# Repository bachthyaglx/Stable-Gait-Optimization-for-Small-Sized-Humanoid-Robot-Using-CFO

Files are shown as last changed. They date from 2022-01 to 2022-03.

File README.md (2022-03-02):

# Stable Gait Optimization for Small Sized Humanoid Robot Using CFO

This research proposes a new way to optimize the gait
design for human robots that allows stable stepping with preset
foot-lifting magnitude. The novel Central Force Optimization
(CFO) algorithm is used to optimize the gait parameters to help
humanoid robot walk steadily. The efficiency of the proposed
method is compared with the GA-Genetic Algorithm, PSOParticle
Swarm Optimization and improved differential
evolution algorithm (MDE-Modified Differential Evolution).
The simulated and experimental results applied on the smallsized
humanoid robot show that the newly proposed algorithm
offers an efficient and stable gait for humanoid robots with
accurate foot-lifting magnitude.

Structural Model



Design Model





Physical Model



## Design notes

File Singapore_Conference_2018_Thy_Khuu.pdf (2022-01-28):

## Stable Gait Optimization for Small-Sized Humanoid Robot Using CFO

Tran Thien Huan, Khuu Bach Thy, Nguyen Ho Hieu Trung, Ho Pham Huy Anh

Abstract—This paper proposes a new way to optimize the gait design for human robots that allows stable stepping with preset foot-lifting magnitude. The novel Central Force Optimization (CFO) algorithm is used to optimize the gait parameters to help humanoid robot walk steadily. The efficiency of the proposed method is compared with the GA-Genetic Algorithm, PSO-Particle Swarm Optimization and improved differential evolution algorithm (MDE-Modified Differential Evolution). The simulated and experimental results applied on the small-sized humanoid robot show that the newly proposed algorithm offers an efficient and stable gait for humanoid robots with accurate foot-lifting magnitude.
Keywords—Gait optimization for humanoid robot, Zero Moment Point (ZMP), inverse and forward kinematics, Central Force Optimization (CFO) algorithm, Modified Differential Evolution (MDE) algorithm, Particle Swarm Optimization (PSO), Genetic Algorithm (GA).
I. INTRODUCTION
The walking gesture of human always contains many so sophisticated points that until now the biped robot still can not fully demonstrate. Therefore, the research of humanoid robot walking mechanism is being developed in different domains. Several standards have been applied to human robots to ensure stable and natural gait. Static walking is the first applied principle, in which the vertical projection of center of mass (COM) on the ground is always in the supporting foot. In other words, humanoid robots can stop at any times when walking without falling apart. By its very simple concept, this principle is efficiently applied to slow-speed biped robots whereby dynamic effects can be ignored [1-2]. Then researchers began to focus on developing dynamic walking [3]. This method allows the humanoid robot to speed up the pace. However, during the biped robot walking process, the robot may fall due to environmental interference and biped can not stop abruptly. Therefore, ZMP-based walking is proposed to help control and to efficiently manipulate biped inertia [4-5].
Recently, several studies have focused on improving the performance of biped robot walking gesture. Huang in [6] introduces a stable gait using the gaiter to use the interpolation function. The method developed by D. Huan, through the GA algorithm, optimizes the generator to help robot move steadily with the least amount of energy [7]. Dip et al. [8] exhibit steady gait at constant velocity using the sine wave generator. Intelligent algorithms are applied in this method to optimize the gait generator for humanoid

Tran Thien Huan is with Ho Chi Minh City University of Technology and Education, , Viet Nam (e-mail: huantt@hcmute.edu.vn)
Khuu Bach Thy, Nguyen Ho Hieu Trung) are with Faculty of Electrical and Electronics Engineering (FEEE), Ho Chi Minh City University of Technology, VNU-HCM, Viet Nam
Ho Pham Huy Anh (corresponding author) is with Faculty of Electrical and Electronics Engineering (FEEE), Ho Chi Minh City University of Technology, VNU-HCM, Viet Nam (e-mail: hphanh@hcmut.edu.vn) robots such as genetic algorithm (GA) [8], algorithm for optimal swarm (PSO) [9], advanced differential algorithm (MDE) [10]. Shaffi in [11] introduces the biped robot which achieves a stable gait by using the Fourier series gait generator. This method uses intelligent algorithms to develop human robot walking movement, such as the bee swarm algorithm [12], the fuzzy TS controller [13], the evolution algorithm [14]. In particular, the very powerful potentiality of the CFO-Central Force Optimization algorithm has not yet to be applied to optimally identify the biped robot's walking gait parameters.
To overcome this gap, this paper proposes the Central Force Optimization (CFO) algorithm used to optimally identify the biped walking gait parameters, based on the dynamic walking method, and use ZMP concept to maintain biped stability. The simulation and empirical results show that the newly proposed CFO algorithm allows optimal identification of the gait parameters for the biped robot to obtain steady gait with accurate foot-lifting magnitude. Small-sized humanoid robot model, namely HUBOT-5, is used to investigate the experimental results.

II. HUMANOID ROBOT MODEL
Small-sized humanoid robot (HUBOT – 5) has the upper torso and two legs as described in figure 1. Each leg consists of 3 parts, which are femoral, legs, and foot with a total of 6 DOF (Degrees Of Freedom). There are 3 DOF at the hip, 1 at the knee, HUBOT – 5 can mimic the walking gesture of human according to the front size interface (YZ – frontal view) and the side view (XZ – Sagittal view). Total weight of the HUBOT is about 1,5 kg ( including the dynamic actuator, sensor, controller and amplifier) and has a height of about 50 cm. HUBOT – 5 is designed to ensure full dynamic structure, with each dof is corresponding with 1 independent actuator. The Servo DC engine HD – 1501 is used as the actuator. The significant advantage of HD – 1501 is small, compact and light (60 g) with twisted momentum

### 17 kg high. The control signal of the servo is obtained via

MATLAB Simulink with the RS–485 transmission standard.

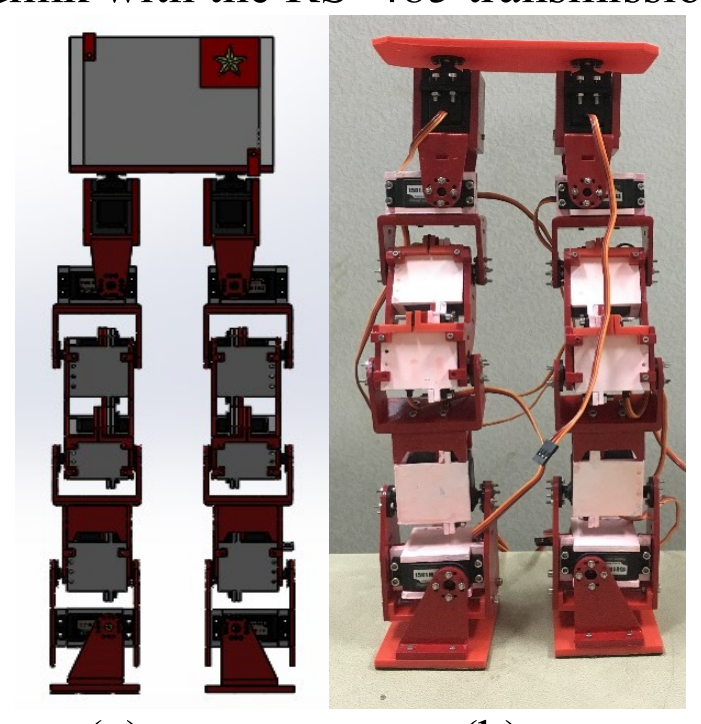
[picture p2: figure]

(a) (b)
Figure 1. HUBOT-5 humanoid robot configuration with 12 DOF

2018 15th International Conference on Control, Automation, Robotics and Vision (ICARCV) Marina Bay Sands Expo and Convention Centre, Singapore, November 18-21, 2018

978-1-5386-9581-4/18/$31.00 ©2018 IEEE | 436

This research only focus on the straight walking gait of humanoid robot, then the upper torso is fixated with only the 10 engines of 10 DOF being controlled and defined in Fig. 2.

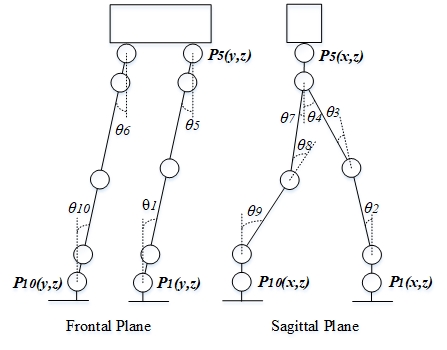
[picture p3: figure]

Figure 2. Humanoid HUBOT-5 structural model.

III. GAIT GENERATION FOT BIPED ROBOT
Four important variables of the humanoid robot that play an essential role in Stable gait generation, are S– Walking length [m], H–Leg lifting [m], h–Leg kneeling [m] and n–Hip swinging are described in Figure 3. In which, d0 is the height of the torso, d1 is the distance between the 2 dof at the knee joints, d2 is the length of the leg, d3 is the length of the femoral and d4 represents the distance between 2 hips.
As described in Figure3, the Hip trajectory P5 =

[ P5 x

, P5 y

, P5z

] and ankle trajectory P1 =[ P1x

, P1y

, P1z

] of the
supporting leg, ankle trajectory P10 =[ P10x

, P10 y

, P10z

] of the
moving legs will depend on 4 variables (S, H, h, n) in both the frontal (YZ-Frontal View) and sagittal (XZ-Sagittal View) interface.

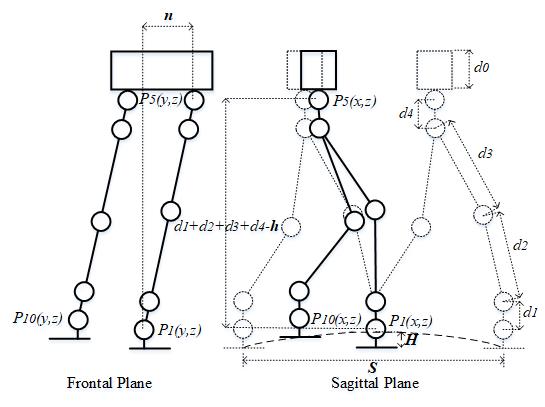
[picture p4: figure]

Figure 3. Four Variables influences the human walking gait of Humanoid Robot HUBOT - 5
The trajectories P1

, P5

, P10 are sine-time dependent, as consulted in [15]. Using the equations described in [10], 10 trajectories of the 2 leg rotary angles of HUBOT-5 in one interval cycle are used to control the walking gait.
Thus the set of four parameters H, h, s and n needs to be carefully selected so that the ZMP parameter ensures that the human robot can walk steadily with the foot-lifting set up in advance. This paper uses the CFO algorithm to satisfactorily address the above problem.

IV. GAIT PARAMETERS OPTIMIZATION USING CFO

A. CFO algorithm
The CFO was introduced in 2007 by R. A. Formato [16]. The algorithm is a somewhat new optimization technique which is nature-based, multi-dimensional, metaheuristic, and based heavily on the gravitational kinematics concept, for example, object fly through space. Unlike other evolutionary algorithm (GA, PSO), CFO does not have randomness characteristics, and that makes the algorithm deterministic. CFO models inspired from the idea of “probe” flying through spaces, the probes will also be attracted by another probe which has equal or greater mass, and the heavier probe will not be influenced. The probes are model based on known equation emphasis on physical attributes, so their path can be mimical and no random changes will be made there after. The position of the probes will be updated continuously, along with their accelerations. The process will continue until global optimum solution is found.
The CFO algorithm consists of following steps:

### 1. Calculate probe initial position, evaluate their value

| and their accelerations, computed their mass.

### 2. Based on the evaluated acceleration, find new

| position of the probes.

### 3. Check if each probe mass and position is located

| inside the decision space, or whether is it converged.
4. Update the fitness value with new position.
5. Update acceleration.
6. Loop until stopping the criterion is satisfied.
CFO notable parameters:
- Alpha coefficient is the influence of probes to each
| other, using the difference of mass. The lower alpha is, the less effect that probe with approx. mass will influence each other.
- Beta, as extended distance, determines the remaining
| influence of probes to each other in space. The lower beta is, the more effect one probe can have to others as great distance.
- Gamma, simply determines accelerations, the higher
| gamma is, the faster the probe accelerate. This can be good when the user wants to quickly find the solution. However, this may have a bad effect on the convergence characteristics.
B. Specify the Objective Function
To evaluate human gait parameters of the humanoid robot, one must define the objective function. The goal of the HUBOT-5 human robot is to achieve a stable gait with a preset lifting amplitude. For this purpose, the ZMP point projection on the foot area according to the ZMP point

437 principle will be used. When the feet touch the ground, the area of the supporting foot is the area between the two feet of the human robot, and when one foot touches the ground, the foot area is the area of the foot touching the ground.
The sum of the squared distance from the ZMP to the center of the supporting foot in 1 step walking of HUBOT – 5 (Equation 1) is the first objective function.

2
1

2

0

T
ZMP | ZMP f | x | y | d | t
(1)
in which T is the stepping cycle and x | y ZMP | ZMP , | is the

coordination of ZMP in the process of the robot to perform the step. The smaller 1

f is the more stable the gait will become.
Additionally, for the humanoid robot to follow the pre-set lighting height value – Href , the difference between the magnitude of the foot lift parameter - and the foot-lift set – Href (Equation 2) is the second objective function. The

smaller 2

f is, the more strictly the lifting magnitude will follow Href .

2 | H | H ref f | | (2)
Thus, in order for HUBOT-5 to have a steady gait with the foot set up in advance, we find the minimum value of the two objective functions 1

f and 2

f , or to find the minimum of the function f as:
- | ² | 2

0

. | 1 | .

T
ZMP | ZMP | ref f | x | y dt | H | H | | | |
(3)
In which, | 0 | 1 is select to prioritize of the (

increase) and difference with the desired lifting magnitude ( decreased).
C. ZMP trajectory calculation
For HUBOT-5, the volume of the suture is very small than the mass of the joints, so the center of the joint is at the end of the joint. Thus, the moment of inertia of the equation is zero, the Equation for ZMP is calculated as (4):

1 1

1

1 1

1

ZMP

ZMP

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

(4)

In equation 4, the mass distribution mi
and coordinates
- x y z i | i | i , , of the stages are defined in Figure 4.

The coordinates Pit x y z , , of the joints are determined

from 10 angles of rotation at one time in one step with the origin coordinatation at the center of the suppoting foot by

means of the geometric relation. In which, | 0 d , 1 d , | 2 d ,
3 d and 4 d are illustrated in Figure 3.

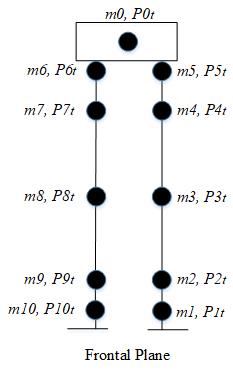
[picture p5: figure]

Figure 4: The mass distribution and coordinates of the stages
Finally, the flow chart to calculate the ZMP trajectory from the set of four gait parameters of the human robot is illustrated in Figure 5.

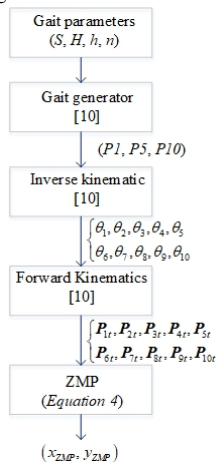
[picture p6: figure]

Figure 5. ZMP calculation flow chart
V. SIMULATION AND EXPERIMENT RESULTS The simulated and experimental results were tested on the HUBOT-5 robot. The physical parameters of the HUBOT-5 robot are presented in Table 1.
TABLE 1. PHYSICAL PARAMTERS OF HUBOT-5
Parameters | Value
0 d | 6.000 cm
1 d | 4.254 cm
2 d | 9.109 cm

438

3 d | 8.063 cm
4 d | 9.345 cm
w | 8.640 cm
- mi i 0 10 | 60 gam

In order to find the appropriate value for the coefficients of the objective function in Equation (3), by selecting
- 0.4 the HUBOT-5 robot has a steady gait with an adjustable foot lift , and this value will be used thorough the testing process of GA, PSO, MDE and proposed CFO.
For optimal GA, PSO, MDE and CFO optimization algorithms, gait parameters are limited as given in Table 2.

TABLE 2. BOUNDARIES FOR 4 WALKING GAIT PARAMTERES OF HUMANOID ROBOT HUBOT-5
Parameters | Lower Bound | Upper Bound
S-Step length | 1.5 cm | 25 cm
H-foot lifting | 0.1 cm | 10 cm
h-kneeling | 0.1 cm | 1.5 cm
n-hip swinging | 0.1 cm | 10 cm

The mathematical properties of GA, PSO, MDE, and CFO optimization algorithms are probabilistic algorithms, so each algorithm performs 10 different training times, each training will repeat 500 times (N = 500) with the same population size (NP = 32) and the same number of variables (n = 4). Table 3 presents GA, PSO, MDE and CFO parameters parameter values.
TABLE 3: PARAMETERS OF GA, PSO, MDE AND CFO ALGORITHM
Method | Paramters | Value
GA | Mutation Probability (MP) Crossover Probability (CP) | 0.4 0.9
PSO | Accelaration factor (C1) Accelaration factor (C2) Inertia Weight (w) | 2.0 2.0 [0.4; 0.9]
MDE | Mutation value (F) Crossover Probability (CR) | Random [0.4; 1.0] Random [0.7; 1.0]
CFO | Alpha Beta Gamma Frep deltaFrep | 0.25 0.35 0.95 0.5 0.05
Specify the lifting height of HUBOT-5 is | 20 H | mm ref | .
Table 4 shows the optimum gait value and best value for the target function of 10 runs corresponding to the GA, PSO, MDE and CFO algorithms. Figure 6 illustrates the mean value of the target function after 10 runs of each algorithm (GA: green, PSO: blue, MDE: red, CFO: reddish purple).

Figure 6: Mean value of f

TABLE 4: OPTIMIZED GAIT VALUE AND BEST TARGET VALUE OF 10 RUNS.
Run | Agorithms | Walking Gait Parameters value
S
(cm)

H
(cm)
| | | h (cm) | n (cm) | Best firness value f(cm)
GA | 15 | 1.99 | 0.80 | 6.86 | 14.88
PSO | 15 | 1.99 | 1.50 | 6.97 | 14.89
MDE | 15 | 1.99 | 0.80 | 6.89 | 14.87

1

CFO | 15 | 2.00 | 0.76 | 6.53 | 14.93
GA | 15 | 1.99 | 0.75 | 6.68 | 14.88
PSO | 15 | 2.00 | 1.50 | 6.97 | 14.89
MDE | 15 | 1.99 | 0.80 | 6.89 | 14.87

2

CFO | 15 | 2.00 | 0.74 | 6.52 | 14.97
GA | 15 | 2.01 | 0.78 | 6.81 | 14.93
PSO | 15 | 2.00 | 0.80 | 6.89 | 14.87
MDE | 15 | 2.00 | 0.80 | 6.89 | 14.87

3

CFO | 15 | 1.99 | 0.50 | 6.63 | 14.98
GA | 15 | 1.99 | 0.82 | 6.97 | 14.90
PSO | 15 | 2.00 | 1.50 | 6.97 | 14.89
MDE | 15 | 2.00 | 0.80 | 6.89 | 14.87

4

CFO | 15 | 2.00 | 1.06 | 6.93 | 14.92
GA | 15 | 1.99 | 0.82 | 6.99 | 14.87
PSO | 15 | 2.00 | 0.80 | 6.89 | 14.87
MDE | 15 | 1.99 | 0.80 | 6.89 | 14.87

5

CFO | 15 | 2.00 | 0.89 | 6.99 | 14.87
GA | 15 | 2.00 | 0.80 | 6.85 | 14.89
PSO | 15 | 2.00 | 0.80 | 6.89 | 14.87
MDE | 15 | 2.00 | 0.80 | 6.89 | 14.87

6

CFO | 15 | 2.00 | 0.78 | 6.69 | 14.87
GA | 15 | 2.01 | 0.81 | 6.93 | 14.94
PSO | 15 | 2.00 | 0.80 | 6.89 | 14.87
MDE | 15 | 2.00 | 0.80 | 6.89 | 14.87

7

CFO | 15 | 2.00 | 0.77 | 6.67 | 14.96
GA | 15 | 1.99 | 0.75 | 6.67 | 14.88
PSO | 15 | 1.99 | 0.80 | 6.89 | 14.87
MDE | 15 | 2.00 | 0.80 | 6.89 | 14.87

8

CFO | 15 | 2.00 | 0.92 | 6.53 | 14.90
GA | 15 | 1.97 | 0.81 | 6.92 | 14.92
PSO | 15 | 1.99 | 0.80 | 6.89 | 14.87
MDE | 15 | 2.00 | 0.80 | 6.89 | 14.87

9

CFO | 15 | 2.00 | 1.04 | 6.89 | 14.88
GA | 15 | 1.99 | 0.79 | 6.84 | 14.90
PSO | 15 | 2.00 | 1.50 | 6.97 | 14.89
MDE | 15 | 1.99 | 0.80 | 6.89 | 14.87

10

CFO | 15 | 2.02 | 0.74 | 6.64 | 14.99

Based on Table 4, the optimum set of parameters for the HUBOT-5 conformation to the objective of 10 runs per GA, PSO, MDE and CFO algorithms is shown in Table 5.

439

TABLE 5. PARAMETRIC SET APPLIED WITH EACH ALGORITHM. Href = 2 cm
Agorithms | Walking Gait Parameters value | Best firness value f(cm)
S (cm) | H (cm) | h (cm) | n (cm)
GA | 15 | 1.99 | 0.82 | 6.99 | 14.87
PSO | 15 | 2.00 | 0.8 | 6.89 | 14.87
MDE | 15 | 2.00 | 0.8 | 6.89 | 14.87
CFO | 15 | 2.00 | 0.89 | 6.99 | 14.87

Figure 7 shows resulted ZMP and COM trajectories when HUBOT-5 steps in a stepping cycle (T = 2s) corresponding to the configurations using GA, PSO, MDE and CFO algorithms. The optimal set of parameters for each of the algorithms in Table 5 shows that the target is reached according to the set foot lift. The ZMP and COM trajectories corresponding to each of the algorithms in Figure 7 show that they are always within the footprint and ensuring steady-state goals.
Based on the results described in Figure 6, the CFO algorithm finds an optimal value of 14.93174983 after an average of 89 generations. The CFO algorithm outperforms GA, PSO, and MDE algorithms in terms of convergence statistic.

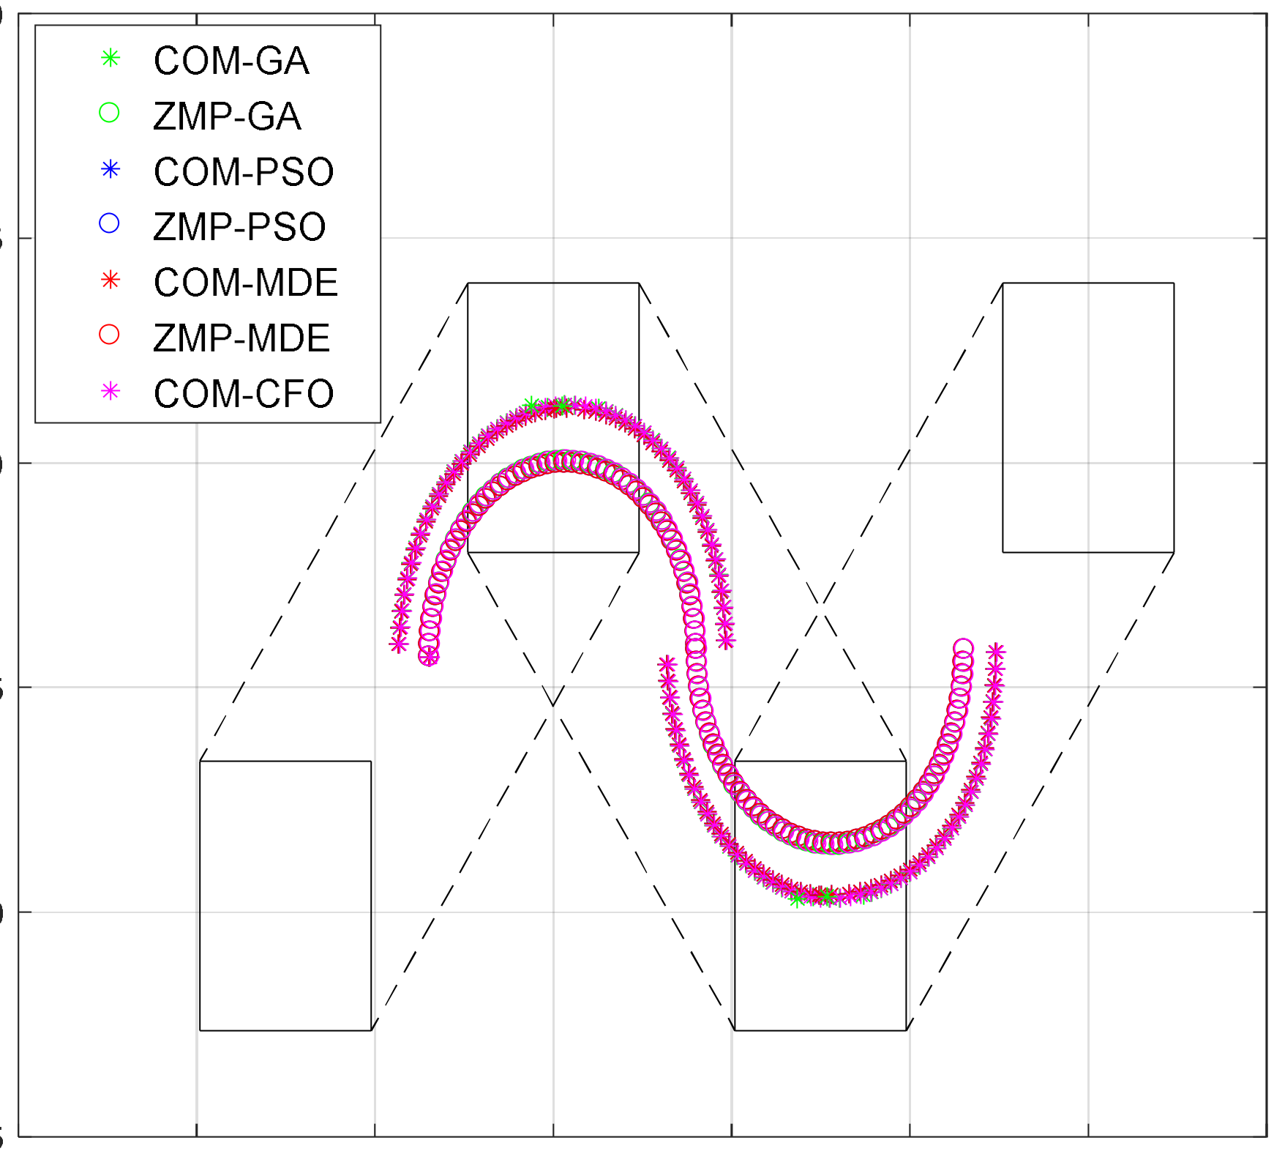
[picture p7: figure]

Figure 7: ZMP and COM survey
Table 6 demonstrates the optimized value of the walking gait parameters to make HUBOT-5 walk steadily with 2 cases of
differnet foot lift magnitude. ( | 2 H | cm ref | và | 4 H | cm ref | )
using CFO.

TABLE 6. RESULTED CFO-BASED OPTIMAL SET OF 4-PARAMETERS
Href (cm) | CFO optimization Results
S (cm) | H (cm) | h (cm) | n (cm)
2.0 | 15 | 2.0 | 0.89 | 6.99
4.0 | 15 | 4.0 | 1.09 | 7.12

Figure 8 show that the HUBOT-5 obtains a pick-up foot-lift with respect to preset value. Figure 9 illustrates the ZMP point and the projection of COM for two different feet lifting amplitude. This shows that the ZMP point is always in the supporting foot area and then ensuring that the HUBOT-5

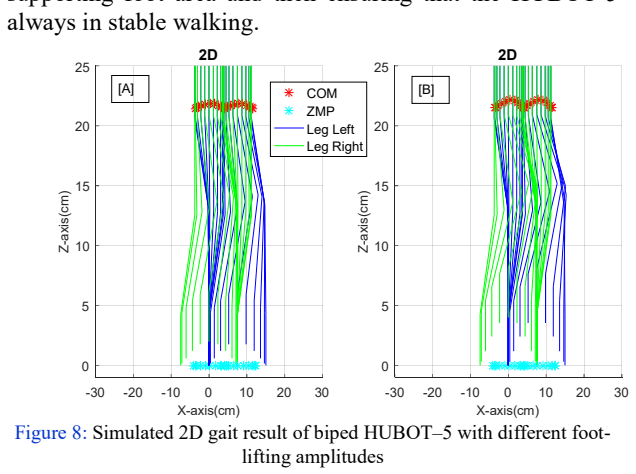
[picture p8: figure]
always in stable walking.; 30 X-axis(cm) 0; 25 Z⁻axis⁽cm⁾; COM ZMP Leg Left Leg Right; lifting amplitudes

Figure 8: Simulated 2D gait result of biped HUBOT–5 with different foot-

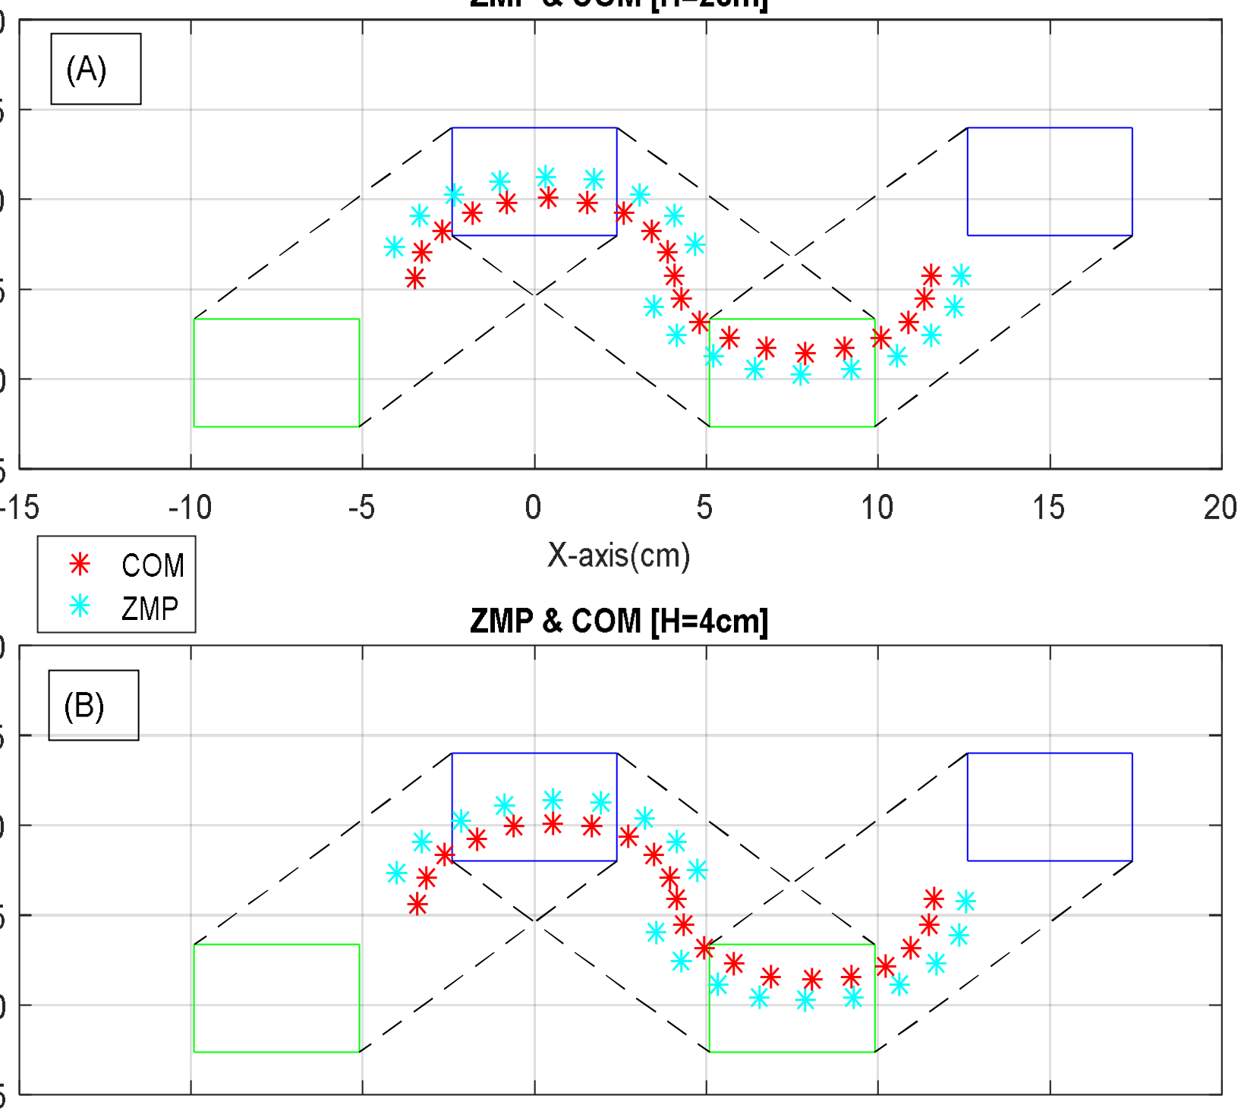
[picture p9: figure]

Figure 9. Resulted ZMP và COM trajectories
Figure 10 demonstrates 10 rotary angle trajectories in one stepping cycle of the 2 legs of HUBOT–5 (

1 , 2 , 3 ,
4 , 5 , 6 , 7 , 8 , 9 , 10 ) when walking with two sets of gait parameters in term to different foot lifts (see Table 9). Using 10 rotary angles to control HUBOT-5 performing two corresponding steps with different foot lifts. Figures 11 illustrates the image of the HUBOT-5 performing a stable
step with the foot lift | 2 H | cm ref | .
Based on the results of the optimization and simulation run shown in Table 6, Figure 8 and Figure 9, as well as the experimental result presented in Figure 11, show that the work of the preset foot-lifting parameters - Href and the four key parameters (S-step length, H-foot lifting, h– kneeling, and n–hip swinging) optimally ensuring the HUBOT-5 biped robot to steadily walking without fallen and keeping pace with preset foot-lift amplitude - using CFO algorithm is feasible.

440

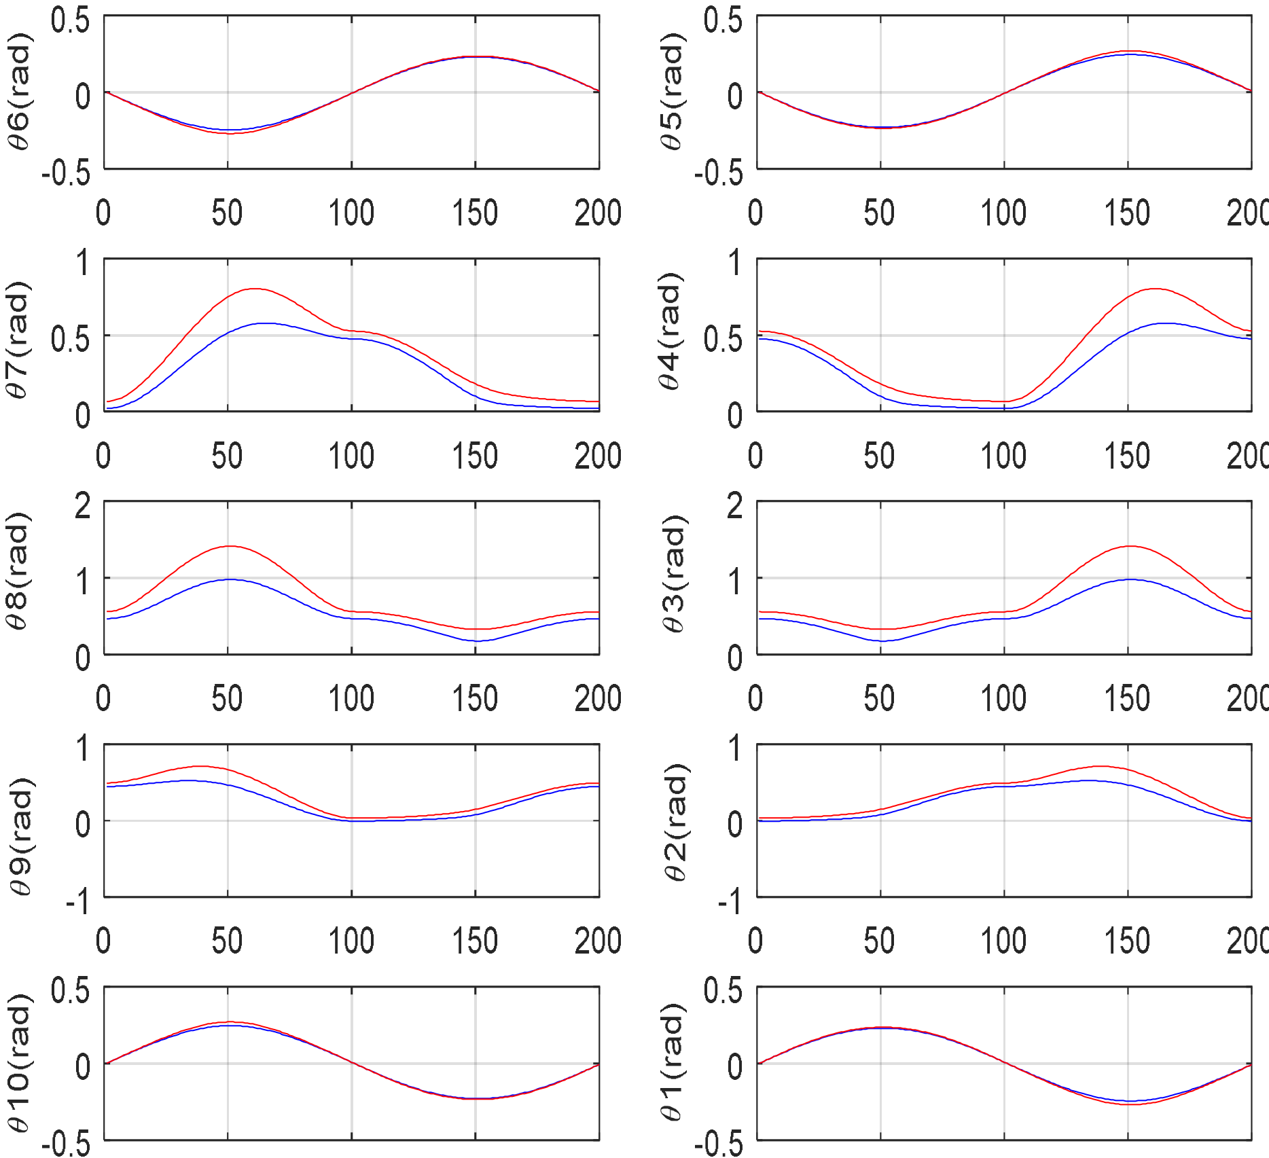
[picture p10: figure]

Figure 10: Trajectories of 10 rotary angles of 2 legs of the HUBOT-5 biped robot

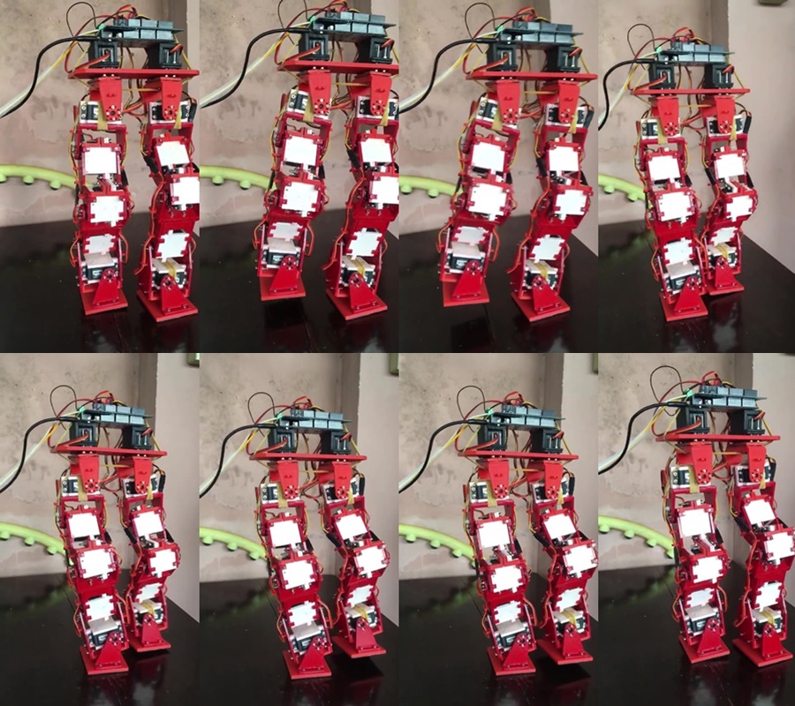
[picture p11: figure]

Figure 11: HUBOT-5 performs stable gait with lifting amplitude value of
2 H | cm ref
VI. | CONCLUSION
This paper introduces a new algorithm that enables dynamic equilibrium shapes for humanoid robots based on CFO algorithms. First, inverse kinematics is used to estimate the position of the motors located in the joints at the two legs of biped. Then, the CFO optimization algorithm is used to optimally identify the best value for humanoid robot gait parameters so that the distance from ZMP to the center of the foot is the smallest with the preset foot-lifting value. The simulated and experimental results of the small-sized

HUBOT-5 biped robot demonstrate that the use of CFO algorithm with an effective target function that allows the biped robot to walk efficiently and steadily with reduced training time.
ACKNOWLEDGMENTS
This research is funded by Vietnam National Foundation for Science and Technology Development (NAFOSTED) under grant number 107.01-2018.10.

REFERENCE

[1] W. T. Miller III, “Real-time neural network control of a biped walking robot”, IEEE Control Systems Magazine. 14(1), pp. 41-48, 1994.
[2] C. L. Shih, “Ascending and descending stairs for a biped robot”, IEEE Transactions on Systems, Man, and Cybernetics. 29(3): pp. 255-268, 1999.
[3] S. Kajita, F. Kanehiro, K. Kaneko, K. Fujiwara, K. Harada, K. Yokoi,
H. Hirukawa, “Biped walking pattern generation by using preview control of Zero-Moment Point”, Proceedings of the IEEE internationalconference on robotics and automation, Taipei, Taiwan, pp. 14-19, 2003.
[4] M.Vukobratovic, et al., “Biped locomotion”, Springer-Verlag, 1990.
[5] J. Mrozowski, J. Awrejcewicz, “Analysis of stability of the human gait”, Journal of Theoreticaland Applied Mechanics, vol. 45, no. 1, pp. 91-98, 2007.
[6] Qiang Huang, Kazuhito Yokoi , Shuuji Kajita, Kenji Kaneko, Hirohiko Arai, Noriho Koyachi and Kazuo Tanie, “Planning Walking Patterns for a Biped Robot”, IEEE Transactions on Robotics and Automation, Vol. 17, No. 3, pp 280-289, 2001.
[7] Van-Huan DAU, Chee-Meng CHEW and Aun-Neow POO, “Optimal Trajectory Generation for Bipedal Robot”, Proceedings IEEE-RAS International Conference on Humanoid Robot, Pittsburgh, PA, USA, pp 603-608, 2007.
[8] Goswami Dip, Vadakkepat Prahlad and Phung Duc Kien, “Genetic algorithm-based optimal bipedal walking gait synthesis considering tradeoff between stability margin and speed”, Robotica, Volume 27, pp. 355-365, 2009.
[9] T. T. Huan and H. P. H. Anh, “Novel Stable Walking for Humanoid Robot Using Particle Swarm Optimization Algorithm”, Journal of Advances in Intelligent Systems Research, Vol. 123, pp. 322- 325, Atlantis Press, July 2015.
[10] Tran Thien Huan, Ho Pham Huy Anh, “Stable gait Optimization for Small-sized Humanoid Robot using MDE”, Special Issue: Measurement, Control & Automation, Vol. 21, No. 1, pp. 63-74, 04-2018.
[11] N. Shafii, L.P. Reis, N. Lau, “Biped Walking using Coronal and Sagittal Movements based on Truncated Fourier Series”, RoboCup-2010: Robot Soccer World Cup XIII, Springer LNAI / LNCS, Vol. 6556, pp.324-335, 2011.
[12] E. Yazdi, V. Azizi, and A. T. Haghighat, “Evolution of biped locomotion using bees algorithm, based on truncated Fourier series”, in Proceedings of the World Congress on Engineering and Computer Science, pp. 378–382, 2010.
[13] Y. Farzaneh, A. Akbarzadeh, A. Akbaria, “Online bioinspired trajectory generation of seven-link biped robot based on T-S fuzzy system”, Applied Soft Computing, 2013.
[14] D. Gong, J. Yan, and G. Zuo, “A review of gait optimization based on evolutionary computation,” Applied Computational Intelligence and Soft Computing, vol. 2010, Article ID 413179, pp. 1-12, 2010.
[15] T. T. Huan and H. P. H. Anh, “Implementation of Novel Stable Walking Method for Small-Sized Biped Robot”, Proceedings The 8th Viet Nam Conference on Mechatronics (VCM-2016), Can Tho, Viet Nam, pp. 283-292, 25-26 November 2016.
[16] R. A. Formato, “Central Force Optimization: A New Metaheuristic with Applications In Applied Electromagnetics”, Progress In Electromagnetics Research (PIER), Vol. 77, pp. 425-491, 2007.

441

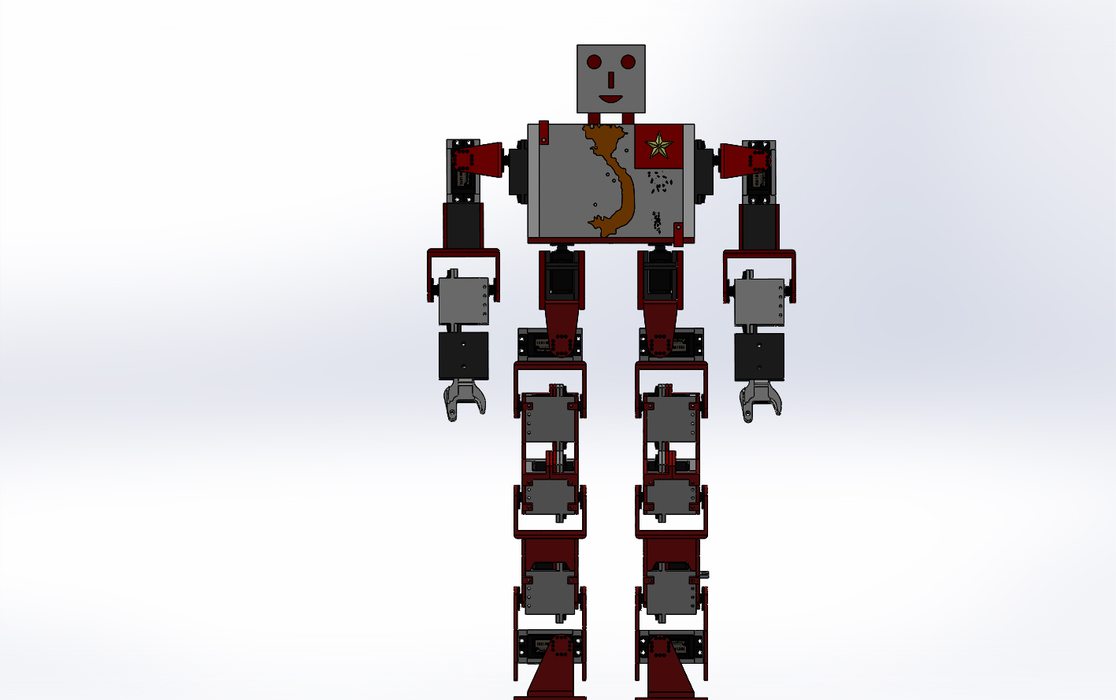
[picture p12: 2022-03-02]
Solidworks/CHAN_ROBOT_NEW.JPG

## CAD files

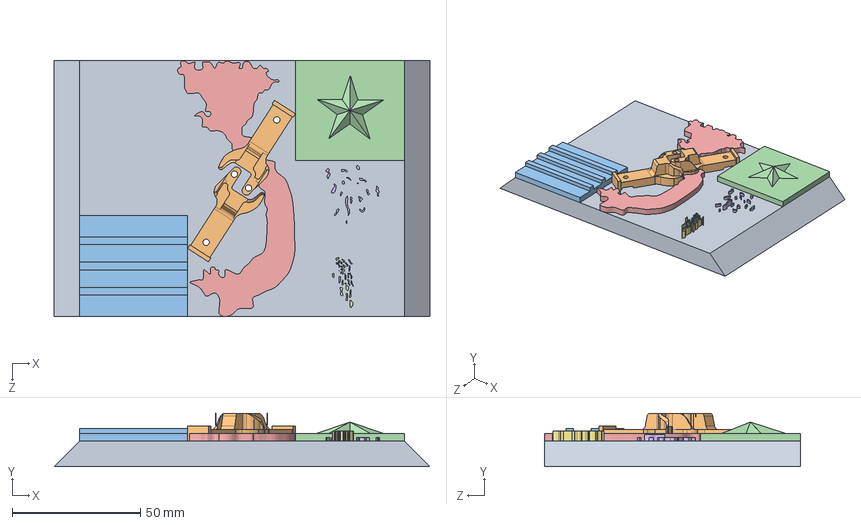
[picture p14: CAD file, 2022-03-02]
Solidworks/TrangTri.SLDASM
146.8 x 20.9 x 100.0 mm
HandShake x 2
CoVang
CoDo
VietNam
HoangSa
TruongSa

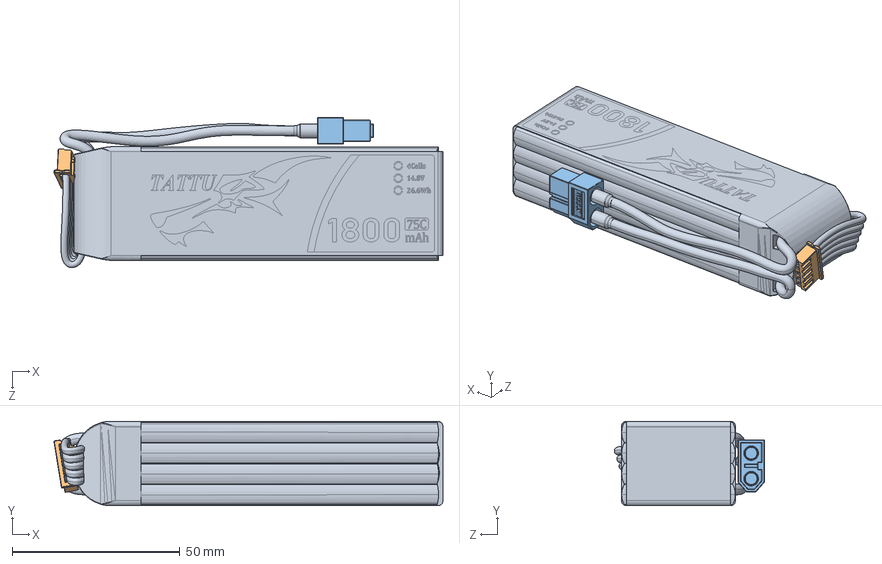
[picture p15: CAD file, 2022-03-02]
Solidworks/LIPO/LIPO.SLDASM
116.0 x 25.2 x 44.8 mm
NUCLEO x 2
JST XHP-4
XT60 Buchse

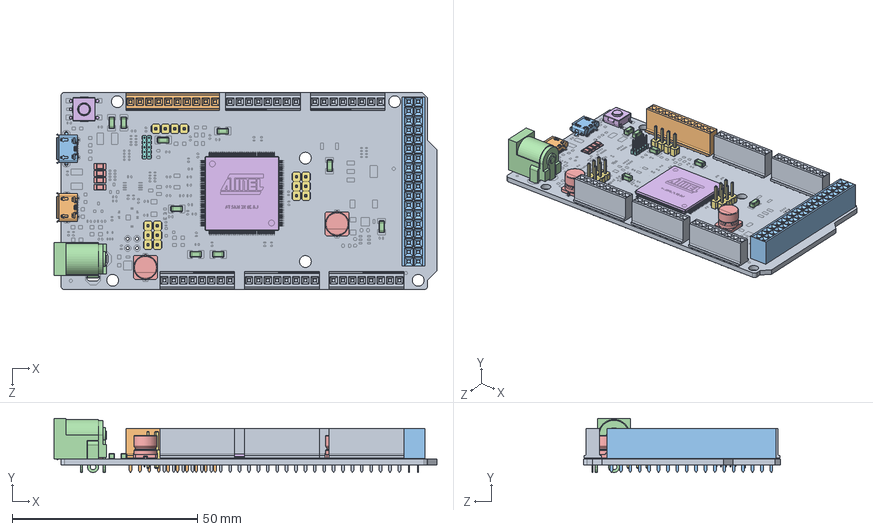
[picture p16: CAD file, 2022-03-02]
Solidworks/ArduinoDue/ARDUINO DUE.SLDASM
103.5 x 14.6 x 53.3 mm
PCB - Arduino
MicroUSB B - Hirose - ZX62D-B-5P8
MicroUSB AB - Hirose - ZX62D-AB-5P8
Power Jack - Kycon - KLDHCX-0202-A
LED - Kingbright - KPT-3216EC x 4
Microchip - Atmel - SAM3X8EAU
Berg Header - 2.54 x 2 x 8
Berg Header - 1.27 x 10
Berg Header Receptacle 2.54 x 8 - FCI - 66951-008LF x 5
Berg Header Receptacle 2.54 x 10 - FCI - 66951-010LF
Berg Header Receptacle 2.54 x 36 - FCI - 66953-018LF
Capacitor x 9
Capacitor - Nichicon - UUR1C101MCL1GS x 2
Switch - ESwitch - TLE3303

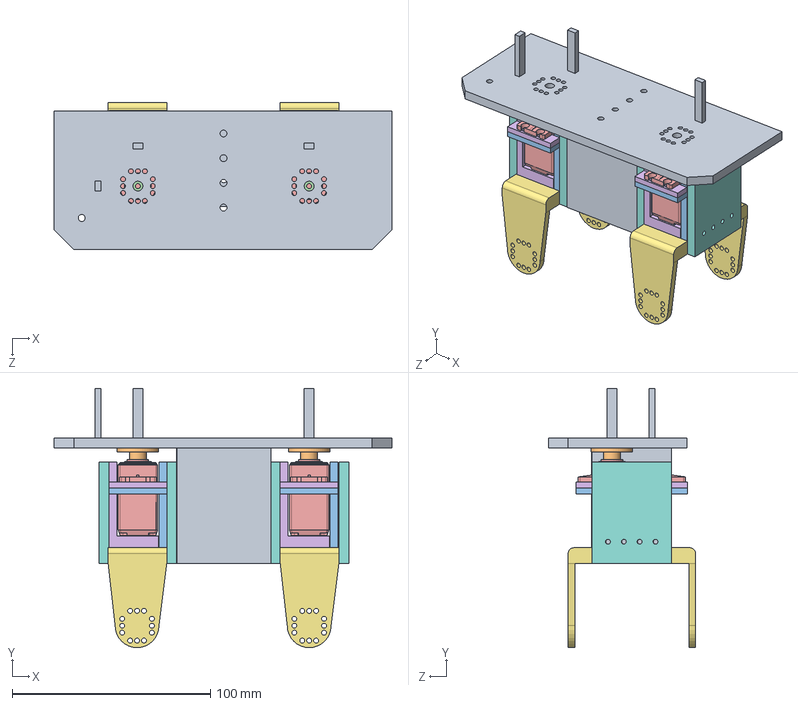
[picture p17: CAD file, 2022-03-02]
Solidworks/Assem1.SLDASM
170.6 x 130.9 x 74.4 mm
Banhrang x 2
Servo Output Shaft x 2
Standard Servo (1501MG) x 2
Khophong

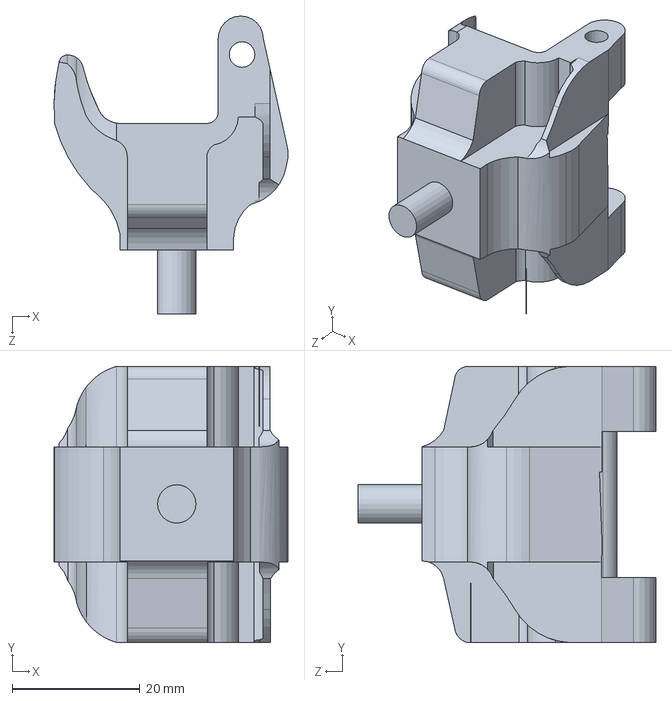
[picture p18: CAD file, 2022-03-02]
Solidworks/Full_HandShake.SLDPRT
36.6 x 43.2 x 46.6 mm

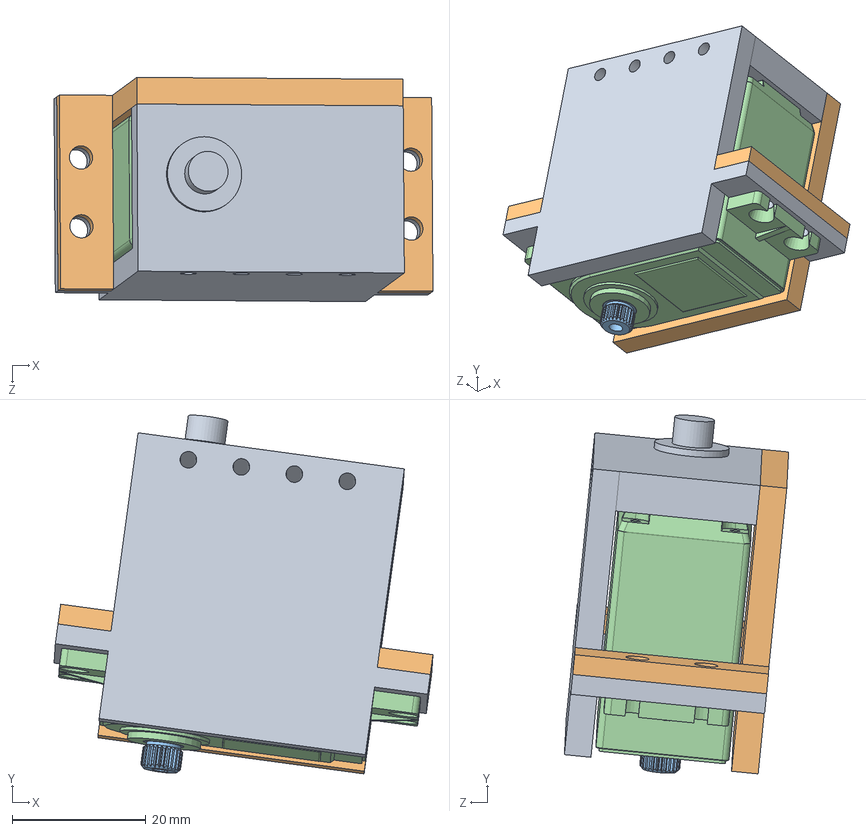
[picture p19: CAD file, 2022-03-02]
Solidworks/BaobocServo.SLDASM
56.7 x 53.7 x 33.5 mm
Servo Output Shaft
Standard Servo (1501MG)

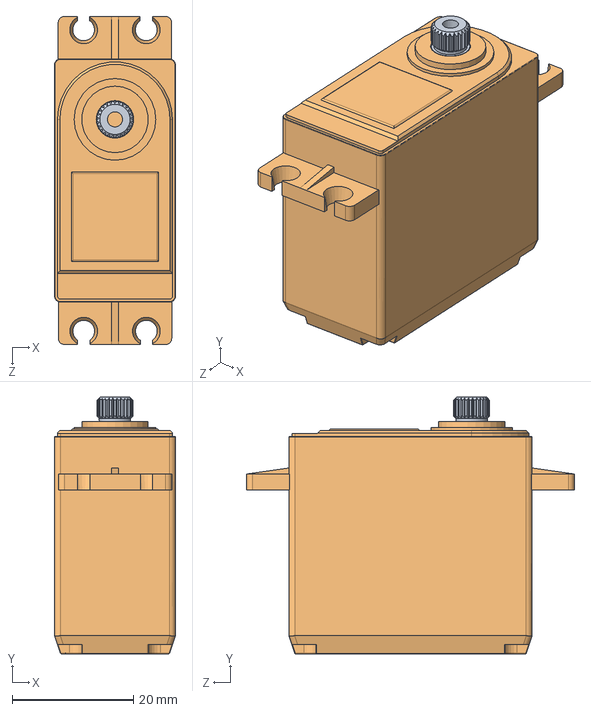
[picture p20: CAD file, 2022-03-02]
Solidworks/Standard Servo Assembly.SLDASM
20.0 x 42.4 x 54.2 mm
Servo Output Shaft
Standard Servo (1501MG)

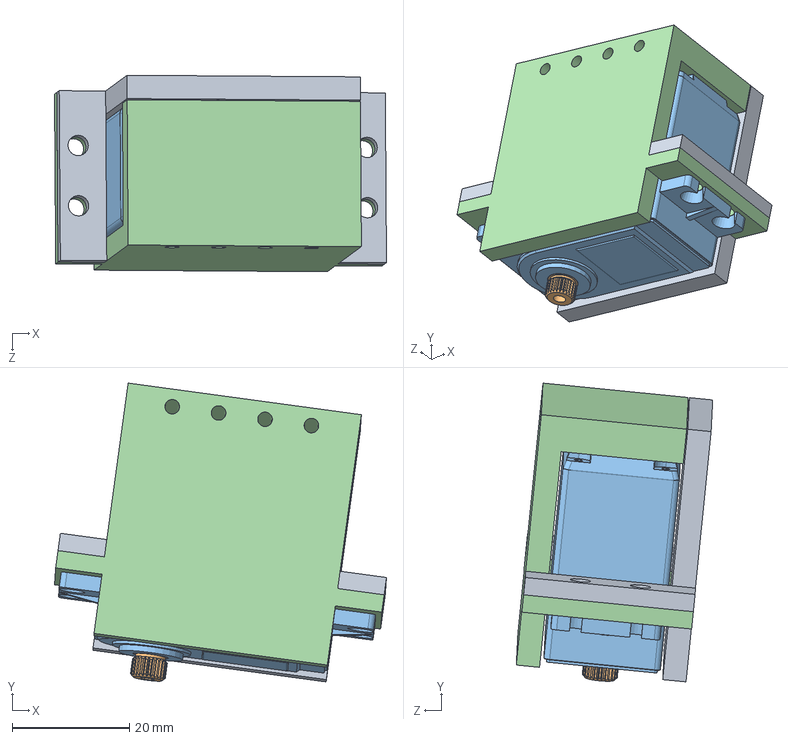
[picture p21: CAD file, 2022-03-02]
Solidworks/BaobocServo_67.SLDASM
56.7 x 51.0 x 33.5 mm
Servo Output Shaft
Standard Servo (1501MG)

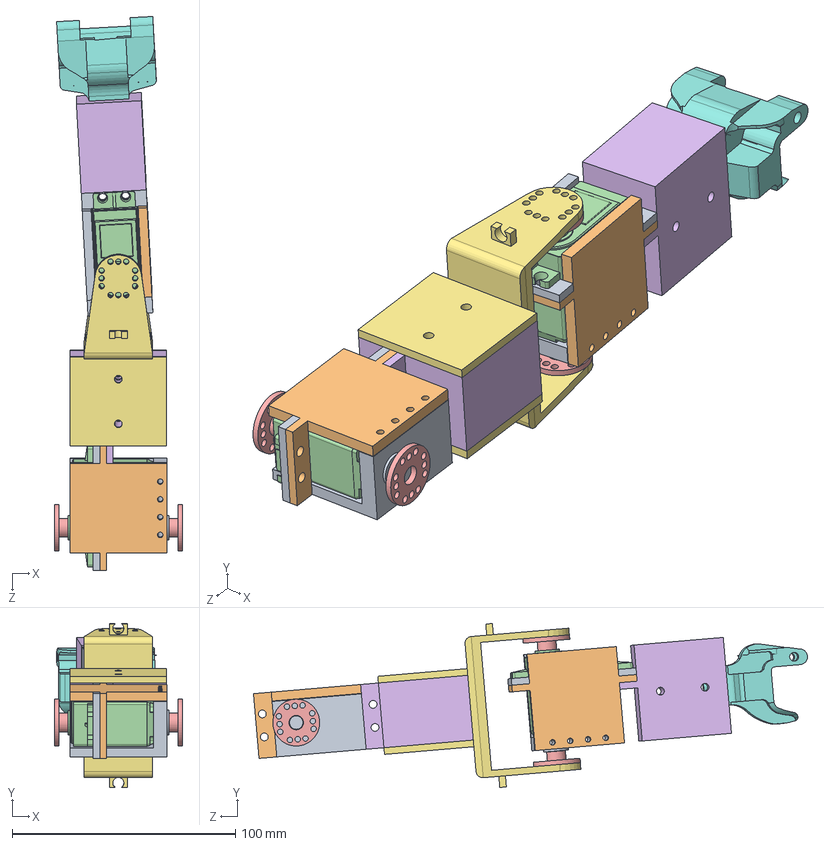
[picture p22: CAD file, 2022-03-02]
Solidworks/TAY_ROBOT.SLDASM
57.4 x 73.5 x 248.3 mm
Servo Output Shaft x 2
Standard Servo (1501MG) x 2
Banhrang x 4
Full_HandShake

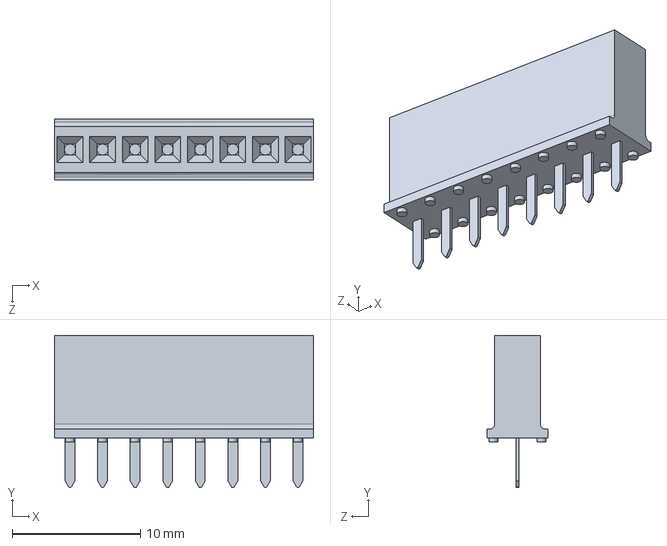
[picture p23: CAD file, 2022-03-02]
Solidworks/ArduinoDue/Berg Header Receptacle 2.54 x 8 - FCI - 66951-008LF.SLDPRT
20.2 x 11.9 x 4.78 mm

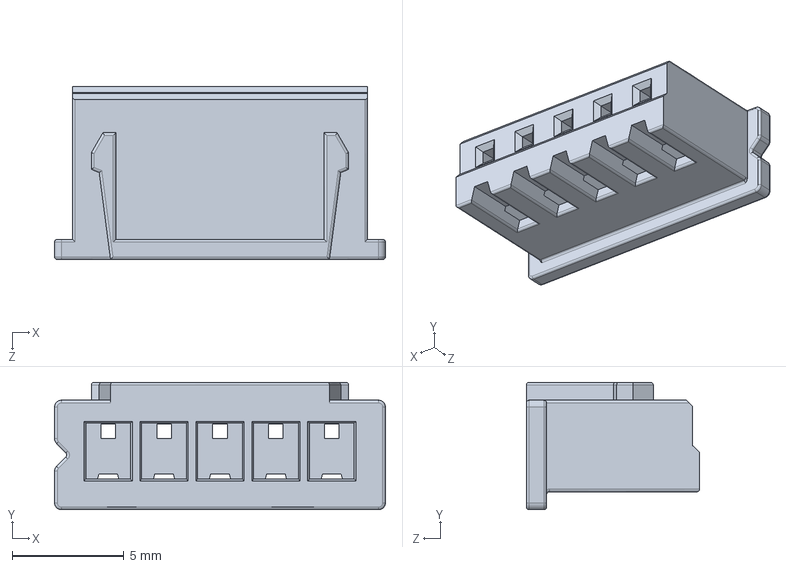
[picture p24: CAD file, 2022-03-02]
Solidworks/LIPO/JST XHP-4.sldprt
14.8 x 5.70 x 7.75 mm

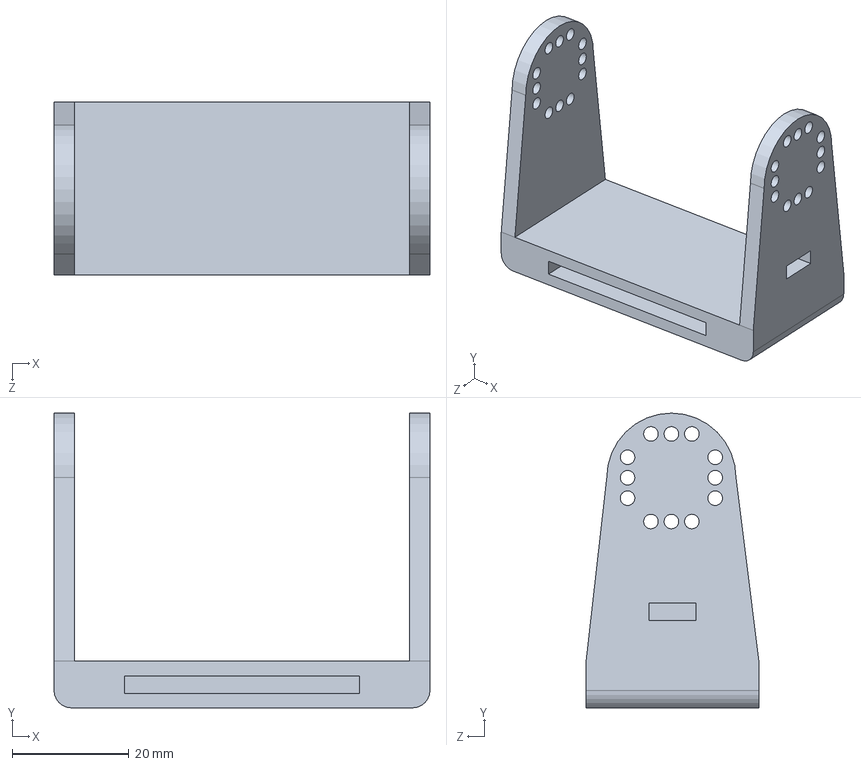
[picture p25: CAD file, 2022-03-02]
Solidworks/Part13.SLDPRT
64.4 x 50.5 x 29.6 mm

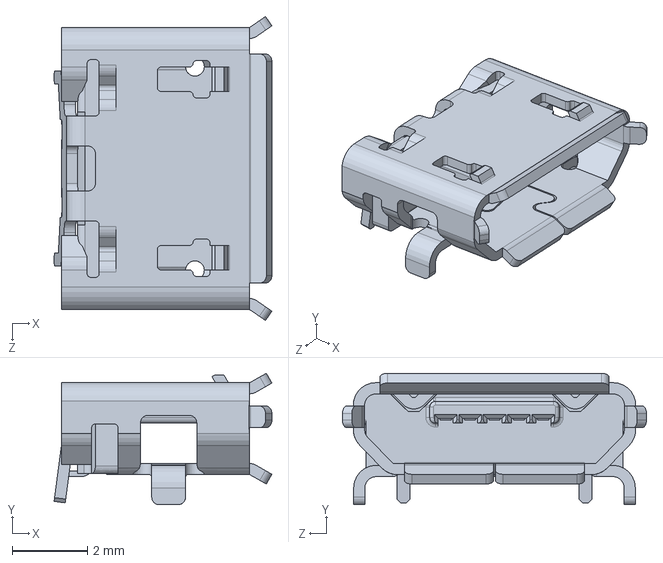
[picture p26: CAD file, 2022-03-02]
Solidworks/ArduinoDue/MicroUSB B - Hirose - ZX62D-B-5P8.SLDPRT
5.80 x 3.50 x 8.09 mm

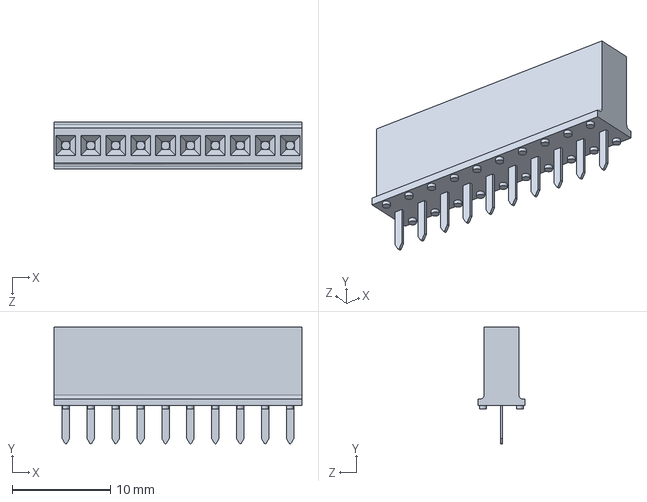
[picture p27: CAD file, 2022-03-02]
Solidworks/ArduinoDue/Berg Header Receptacle 2.54 x 10 - FCI - 66951-010LF.SLDPRT
25.3 x 11.9 x 4.78 mm

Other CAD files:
Solidworks/LIPO/LOGO.SLDPRT
Solidworks/Part22_1.SLDPRT
Solidworks/ArduinoDue/PCB - Arduino.SLDPRT
Solidworks/LIPO/NUCLEO.SLDPRT
Solidworks/ArduinoDue/Berg Header - 1.27 x 10.SLDPRT
Solidworks/ArduinoDue/Berg Header - 2.54 x 2.SLDPRT
Solidworks/ArduinoDue/Berg Header Receptacle 2.54 x 36 - FCI - 66953-018LF.SLDPRT
Solidworks/ArduinoDue/Capacitor - Nichicon - UUR1C101MCL1GS.SLDPRT
Solidworks/ArduinoDue/Capacitor.SLDPRT
Solidworks/ArduinoDue/LED - Kingbright - KPT-3216EC.SLDPRT
Solidworks/ArduinoDue/MicroUSB AB - Hirose - ZX62-AB-5PA.SLDPRT
Solidworks/ArduinoDue/MicroUSB AB - Hirose - ZX62D-AB-5P8.SLDPRT
Solidworks/ArduinoDue/Microchip - Atmel - SAM3X8EAU.SLDPRT
Solidworks/ArduinoDue/Power Jack - Kycon - KLDHCX-0202-A.SLDPRT
Solidworks/ArduinoDue/Switch - ESwitch - TLE3303.SLDPRT
Solidworks/Banchan.SLDPRT
Solidworks/Banhrang.SLDPRT
Solidworks/CoDo.SLDPRT
Solidworks/CoVang.SLDPRT
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

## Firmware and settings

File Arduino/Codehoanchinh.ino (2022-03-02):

#include <Servo.h>
 
Servo myservo1, myservo2, myservo3, myservo4, myservo5, myservo6, myservo7, myservo8, myservo9, myservo10;
float pi =3.14159265358979;
float deta1[] = { 0.0, 0.0148726655339867, 0.047100426080415592, 0.0616794804016107,
    0.0934211305162752, 0.10732633642513428, 0.1207595777410759,
    0.15108969032142297, 0.16333059014000989, 0.17486151048710388,
    0.18561419432603088, 0.19552643509949888, 0.20454222128610089,
    0.23006508400232217, 0.2371449094173782, 0.26065091460807949,
    0.26564519993145047, 0.26955567139979947, 0.27236274388383247,
    0.27405251960573146, 0.27461669824910645, 0.27461669824910645,
    0.27461669824910645, 0.27461669824910645, 0.27461669824910645,
    0.27461669824910645, 0.27461669824910645, 0.27461669824910645,
    0.27461669824910645, 0.27461669824910645, 0.27461669824910645,
    0.27461669824910645, 0.27461669824910645, 0.27461669824910645,
    0.27461669824910645, 0.27461669824910645, 0.27461669824910645,
    0.27461669824910645, 0.27461669824910645, 0.27461669824910645,
    0.27461669824910645, 0.27461669824910645, 0.27461669824910645,
    0.27461669824910645, 0.27461669824910645, 0.27461669824910645,
    0.27461669824910645, 0.27461669824910645, 0.27461669824910645,
    0.27461669824910645, 0.27461669824910645, 0.27461669824910645,
    0.27461669824910645, 0.27461669824910645, 0.27461669824910645,
    0.27461669824910645, 0.27461669824910645, 0.27461669824910645,
    0.27461669824910645, 0.27461669824910645, 0.27461669824910645,
    0.27461669824910645, 0.27461669824910645, 0.27461669824910645,
    0.27461669824910645, 0.27461669824910645, 0.27461669824910645,
    0.27461669824910645, 0.27461669824910645, 0.27461669824910645,
    0.27461669824910645, 0.27461669824910645, 0.27461669824910645,
    0.27461669824910645, 0.27461669824910645, 0.27461669824910645,
    0.27461669824910645, 0.27461669824910645, 0.27461669824910645,
    0.27461669824910645, 0.27461669824910645, 0.27405251960573146,
    0.27236274388383247, 0.26955567139979947, 0.26564519993145047,
    0.24319762208813617, 0.2371449094173782, 0.23006508400232217,
    0.22199551380604421, 0.21297972761944217, 0.2030674868459742,
    0.19231480300704717, 0.18078388265995318, 0.16854298284136626,
    0.13821287026101908, 0.12477962894507749, 0.11087442303621858,
    0.0616794804016107, 0.047100426080415696, 0.0148726655339867, 0.0,
    -0.049780070002929694, -0.099466834023432982, -0.11406125794745978,
    -0.14583245850895066, -0.17723885241966236, -0.19074203783109278,
    -0.20371400368706777, -0.21607777784403076, -0.21030784804972946,
    -0.27360352529093535, -0.28372989344000538, -0.29299036804415735,
    -0.30133393792645735, -0.30871502342461032, -0.28018682530412575,
    -0.25062098475317018, -0.28980089161856176, -0.29298207240716079,
    -0.27759808135772346, -0.29599398904706375, -0.27892326071186146,
    -0.31422570480498807, -0.31463372027374004, -0.33250592655127037,
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
float deta2[]={ -0.0094295989905326914, -0.00944473964957759, -0.00948468893467459,
    0.042826788956240695, 0.0427969964660075, 0.042823235494214094,
    0.0429527861163039, 0.0432420520625665, 0.0437555581352882,
    0.062017918829820391, 0.063198979101840788, 0.064831489009209389,
    0.066995466667166589, 0.069768686220944481, 0.073223638673747191,
    0.077424417682061486, 0.082423737752505583, 0.08826031807693549,
    0.094956857765659389, 0.1025187827760177, 0.110933866354852,
    0.1198946227144774, 0.1290972500928366, 0.13852218080136158,
    0.14815007313954959, 0.1405085354260103, 0.16793859956549159,
    0.17806180251875958, 0.18831311502044759, 0.19867448035313359,
    0.20912810696527259, 0.23710976055185287, 0.24769559361559387,
    0.24086860829483059, 0.25151865758600961, 0.26217598527847857,
    0.2728244001190116, 0.28344798909467661, 0.29403112505951856,
    0.30455847623635457, 0.33246831011712291, 0.34283933660398391,
    0.35311047811605389, 0.39817430119758951, 0.40820398705600047,
    0.41809286135509749, 0.4278280748150865, 0.43739721003342547,
    0.44678830409361348, 0.45598987180246148, 0.46499092935452746,
    0.45632772570396518, 0.46489693656844716, 0.47323593307894418,
    0.48133597529786815, 0.45428235760333258, 0.4618807711505416,
    0.46921781516085259, 0.47628735772292657, 0.4830839704125926,
    0.47214965437388534, 0.47838702788129234, 0.48433958753983331,
    0.49000489349065329, 0.477927998281455, 0.483014629624837, 0.487811446709145,
    0.492319220438012, 0.49653954976291, 0.48302157664939371,
    0.45176857714564306, 0.45514455085911815, 0.47570117597238842,
    0.47853768741964336, 0.48111404520540041, 0.46598446723156611,
    0.45061059144846982, 0.45245487886602587, 0.45407401174869289,
    0.42057216362060529, 0.42177401756958427, 0.42311077529498625,
    0.42492652658169322, 0.42722819649379024, 0.43000289386343021,
    0.43321825342525727, 0.45427701936658949, 0.45820601500776847,
    0.4623787062128365, 0.46670528054991856, 0.47108939263662153,
    0.47543160633249848, 0.47963265700714452, 0.48359641820949051,
    0.48723250821000652, 0.49045851341491653, 0.49320183466189449,
    0.49540117928114047, 0.49700772881028654, 0.49798601228493755,
    0.49831451076981648, 0.4983311346823045, 0.53329418824614416,
    0.53341000596246113, 0.49871014849323347, 0.49905000336752647,
    0.49957394808975453, 0.50033932383323654, 0.53631369965480213,
    0.5377455434749131, 0.591960513312268, 0.50702610669714554,
    0.50988055675576649, 0.600558599632231, 0.49982971441924623,
    0.609127940215519, 0.614287841771359, 0.620008501131459, 0.626255255601055,
    0.632980396079763, 0.640124420582907, 0.69972458539319182,
    0.70675613047836183, 0.74844539949250943, 0.75494025435178047,
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
float deta3[]={ 0.43899390175396935, 0.43865919555827537, 0.43766742665999436,
    0.43605547288459134, 0.43388421598056037, 0.43123763328368436,
    0.42822145467170936, 0.42496131763390832, 0.42160034230008336,
    0.41829604698234835, 0.41521653839186135, 0.41253594472376531,
    0.41042911845946639, 0.4090657194871693, 0.40860389204188929,
    0.40918385678662639, 0.4109218300744294, 0.41390473031261532,
    0.4181861145261353, 0.42378369752392431, 0.43067865119946935,
    0.43823612176994831, 0.44583110969314432, 0.45343333161527233,
    0.46101346629320239, 0.46854319924580734, 0.47599525523012332,
    0.48334342084324233, 0.49056255928197734, 0.49762861902140731,
    0.50451863791191132, 0.51121074394941035, 0.51768415374992938,
    0.52391916955925832, 0.52989717545220139, 0.53560063322301033,
    0.54101307833793233, 0.54611911621059939, 0.5509044189695933,
    0.55535572281272338, 0.55946082598277436, 0.56320858735279633,
    0.56658892557377538, 0.5695928187124274, 0.5722123042903503,
    0.57444047962685529, 0.57627150238528035, 0.57770059122554529,
    0.57872402647324839, 0.5793391507269543, 0.57954436933963838,
    0.5793391507269543, 0.57872402647324839, 0.57770059122554529,
    0.57627150238528035, 0.57444047962685529, 0.5722123042903503,
    0.5695928187124274, 0.56658892557377538, 0.56320858735279633,
    0.55946082598277436, 0.55535572281272338, 0.5509044189695933,
    0.54611911621059939, 0.54101307833793233, 0.53560063322301033,
    0.52989717545220039, 0.52391916955925832, 0.51768415374992938,
    0.51121074394941035, 0.50451863791191132, 0.49762861902140731,
    0.49056255928197734, 0.48334342084324233, 0.47599525523012332,
    0.46854319924580734, 0.46101346629320239, 0.45343333161527233,
    0.44583110969314432, 0.43823612176994831, 0.43067865119946935,
    0.42378369752392431, 0.4181861145261353, 0.41390473031261532,
    0.4109218300744294, 0.40918385678662639, 0.40860389204188929,
    0.4090657194871693, 0.41042911845946639, 0.41253594472376531,
    0.41521653839186135, 0.41829604698234835, 0.42160034230008336,
    0.42496131763390832, 0.42822145467170936, 0.43123763328368436,
    0.43388421598056037, 0.43605547288459134, 0.43766742665999436,
    0.43865919555827537, 0.43899390175396935, 0.43927828740108632,
    0.44014302974865938, 0.4416223722410223, 0.44377168704840231,
    0.44666495929680239, 0.45039134440271333, 0.4550508991639044,
    0.46074963966048033, 0.46759413807254735, 0.47568592717755032,
    0.48511602344625437, 0.49595989490403736, 0.50827317923851634,
    0.52208839881289737, 0.53741282866241336, 0.55422756523398631,
    0.57248773571592437, 0.5921236976563653, 0.61304301837585229,
    0.63513299809344836, 0.65781599129911639, 0.68054877104396838,
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
float deta5[]={ 0.570596548384105, 0.570276982847455, 0.569325163234272, 0.567761609127784,
    0.565620144713986, 0.562947322988903, 0.559801593754838, 0.556252190770775,
    0.552377709364228, 0.548264345871904, 0.544003777009397, 0.539690673433932,
    0.535419869511676, 0.531283250985601, 0.527366471087519, 0.523745656823941,
    0.5204843100413, 0.517630629955056, 0.515215474479853, 0.513251132467283,
    0.511731002563993, 0.510327716774848, 0.508720077319684, 0.506897368533287,
    0.504849610873028, 0.50256758901923, 0.500042873384007, 0.497267836043859,
    0.494235661980906, 0.49094035638765, 0.487376748666015, 0.483540493636876,
    0.479428070373655, 0.475036778983804, 0.470364735585567, 0.465410865663908,
    0.460174895938297, 0.454657344835299, 0.448859511629451, 0.442783464295745,
    0.436432026104971, 0.429808760988132, 0.422917957697041, 0.415764612794044,
    0.408354412513557, 0.400693713550964, 0.3927895228494, 0.384649476471326,
    0.376281817658841, 0.367695374203699, 0.358899535264317, 0.349904227782252,
    0.340719892664064, 0.331357460905864, 0.321828329846675, 0.312144339742899,
    0.302317750859186, 0.292361221270951, 0.282287785570224, 0.27211083465958,
    0.261844096808322, 0.251501620130864, 0.241097756629193, 0.230647147919379,
    0.220164712735967, 0.209665636277663, 0.199165361422545, 0.188679581800736,
    0.178224236666509, 0.167815507459562, 0.157469815885927, 0.147203823281949,
    0.137034430949192, 0.126978781063202, 0.117054257664326, 0.107278487133901,
    0.0976693374444485, 0.0882449153489628, 0.0790235605441685,
    0.0700238357091736, 0.0612645111897149, 0.0530327997887686,
    0.0456194655042725, 0.0390364113786546, 0.0332788137708287,
    0.028325480921199, 0.0241400427550728, 0.0206728745591745,
    0.0178635823264033, 0.0156438342536198, 0.0139403158350127,
    0.0126776107296226, 0.0117808553727124, 0.0111780695041916,
    0.0108021165414756, 0.0105922899485417, 0.0104955513984389,
    0.0104674636832244, 0.0104728679294812, 0.0104863533531107,
    0.0104925610639256, 0.0107603227985559, 0.0115685966221744,
    0.0129321213982211, 0.014874708634942, 0.0174281260090492, 0.020630566392732,
    0.0245247454104413, 0.0291556951253379, 0.034568349717293,
    0.0408050465447719, 0.0479030868288826, 0.0558925082280437,
    0.0647942122857754, 0.0746185619534811, 0.0853645211263836,
    0.0970193561421169, 0.109558867263955, 0.1229480747348, 0.137142254975579,
    0.15208821019003, 0.167530916145243, 0.183232150804926, 0.199159328464017,
    0.215280923794422, 0.231566253209406, 0.247985274477157, 0.26450840446592,
    0.281106354532458, 0.297749982955741, 0.314410163894566, 0.331057672554007,
    0.347663086535734, 0.364196703683844, 0.380628477088192, 0.396927968241317,
    0.413064319634172, 0.429006248292304, 0.444722061871279, 0.460179698923934,
    0.475346794802019, 0.490190774346761, 0.504678972050566, 0.51877877973944,
    0.532457821048581, 0.545684151070353, 0.558426478585363, 0.57065440729519,
    0.582338691519204, 0.593451500961433, 0.603966688459016, 0.613860054147588,
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
float deta6[]={ 0.0, 0.0148726655339867, 0.0296471335604723, 0.0442261878816674,
    0.0585145454763886, 0.0724197513852477, 0.0858529927011893,
    0.0987298127615931, 0.11097071258018, 0.122501632927274, 0.133254316766201,
    0.143166557539669, 0.152182343726271, 0.160251913922549, 0.167331739337605,
    0.173384452008363, 0.178378737331734, 0.182289208800083, 0.185096281284116,
    0.186786057006015, 0.18735023564939, 0.18735023564939, 0.18735023564939,
    0.18735023564939, 0.18735023564939, 0.18735023564939, 0.18735023564939,
    0.18735023564939, 0.18735023564939, 0.18735023564939, 0.18735023564939,
    0.18735023564939, 0.18735023564939, 0.18735023564939, 0.18735023564939,
    0.18735023564939, 0.18735023564939, 0.18735023564939, 0.18735023564939,
    0.18735023564939, 0.18735023564939, 0.18735023564939, 0.18735023564939,
    0.18735023564939, 0.18735023564939, 0.18735023564939, 0.18735023564939,
    0.18735023564939, 0.18735023564939, 0.18735023564939, 0.18735023564939,
    0.18735023564939, 0.18735023564939, 0.18735023564939, 0.18735023564939,
    0.18735023564939, 0.18735023564939, 0.18735023564939, 0.18735023564939,
    0.18735023564939, 0.18735023564939, 0.18735023564939, 0.18735023564939,
    0.18735023564939, 0.18735023564939, 0.18735023564939, 0.18735023564939,
    0.18735023564939, 0.18735023564939, 0.18735023564939, 0.18735023564939,
    0.18735023564939, 0.18735023564939, 0.18735023564939, 0.18735023564939,
    0.18735023564939, 0.18735023564939, 0.18735023564939, 0.18735023564939,
    0.18735023564939, 0.18735023564939, 0.186786057006015, 0.185096281284116,
    0.182289208800083, 0.178378737331734, 0.173384452008363, 0.167331739337605,
    0.160251913922549, 0.152182343726271, 0.143166557539669, 0.133254316766201,
    0.122501632927274, 0.11097071258018, 0.0987298127615931, 0.0858529927011892,
    0.0724197513852476, 0.0585145454763887, 0.0442261878816674,
    0.0296471335604724, 0.0148726655339867, 0.0, -0.0148734849630431,
    -0.0296536639436598, -0.0442480878676866, -0.0585659959092342,
    -0.0725190973000026, -0.086022282711433, -0.098994248567408,
    -0.111358022724371, -0.123041385450013, -0.133977185131389,
    -0.144103553280459, -0.153364027884611, -0.161707597766911,
    -0.169088683265064, -0.175467070184466, -0.180807814673397,
    -0.185081136498902, -0.188262317287501, -0.190331618758007,
    -0.191274233927404, -0.191656798112145, -0.192052657165385,
    -0.192460672634137, -0.192879586391724, -0.193308018094583,
    -0.193744464025432, -0.194187297498276, -0.194634770991492,
    -0.195085020160746, -0.195536069863225, -0.195985842298315,
    -0.196432167337182, -0.196872795074696, -0.197305410592226,
    -0.197727650869459, -0.198137123728666, -0.198531428636931,
    -0.198908179132511, -0.199265026582586, -0.199599684923483,
    -0.19990995598329, -0.200193754943183, -0.200449135460084,
    -0.200674313951638, -0.200867692536814, -0.201027880133013,
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
float deta7[]={ 0.0, 0.0148734849630431, 0.0296536639436598, 0.0442480878676866,
    0.0585659959092342, 0.0725190973000026, 0.086022282711433, 0.098994248567408,
    0.111358022724371, 0.123041385450013, 0.133977185131389, 0.144103553280459,
    0.153364027884611, 0.161707597766911, 0.169088683265064, 0.175467070184466,
    0.180807814673397, 0.185081136498902, 0.188262317287501, 0.190331618758007,
    0.191274233927404, 0.191656798112145, 0.192052657165385, 0.192460672634137,
    0.192879586391724, 0.193308018094583, 0.193744464025432, 0.194187297498276,
    0.194634770991492, 0.195085020160746, 0.195536069863225, 0.195985842298315,
    0.196432167337182, 0.196872795074696, 0.197305410592226, 0.197727650869459,
    0.198137123728666, 0.198531428636931, 0.198908179132511, 0.199265026582586,
    0.199599684923483, 0.19990995598329, 0.200193754943183, 0.200449135460084,
    0.200674313951638, 0.200867692536814, 0.201027880133013, 0.201153711234138,
    0.201244261933695, 0.201298862811921, 0.201317108374641, 0.201298862811921,
    0.201244261933695, 0.201153711234138, 0.201027880133013, 0.200867692536814,
    0.200674313951638, 0.200449135460084, 0.200193754943183, 0.19990995598329,
    0.199599684923483, 0.199265026582586, 0.198908179132511, 0.198531428636931,
    0.198137123728666, 0.197727650869459, 0.197305410592226, 0.196872795074696,
    0.196432167337182, 0.195985842298315, 0.195536069863225, 0.195085020160746,
    0.194634770991492, 0.194187297498275, 0.193744464025432, 0.193308018094583,
    0.192879586391724, 0.192460672634137, 0.192052657165385, 0.191656798112145,
    0.191274233927404, 0.190331618758007, 0.188262317287501, 0.185081136498902,
    0.180807814673397, 0.175467070184466, 0.169088683265064, 0.161707597766911,
    0.153364027884611, 0.144103553280459, 0.133977185131389, 0.123041385450013,
    0.111358022724371, 0.098994248567408, 0.0860222827114329, 0.0725190973000025,
    0.0585659959092342, 0.0442480878676867, 0.0296536639436599,
    0.0148734849630431, 0.0, -0.0148726655339867, -0.0296471335604723,
    -0.0442261878816674, -0.0585145454763886, -0.0724197513852477,
    -0.0858529927011893, -0.0987298127615931, -0.11097071258018,
    -0.122501632927274, -0.133254316766201, -0.143166557539669,
    -0.152182343726271, -0.160251913922549, -0.167331739337605,
    -0.173384452008363, -0.178378737331734, -0.182289208800083,
    -0.185096281284116, -0.186786057006015, -0.18735023564939, -0.18735023564939,
    -0.18735023564939, -0.18735023564939, -0.18735023564939, -0.18735023564939,
    -0.18735023564939, -0.18735023564939, -0.18735023564939, -0.18735023564939,
    -0.18735023564939, -0.18735023564939, -0.18735023564939, -0.18735023564939,
    -0.18735023564939, -0.18735023564939, -0.18735023564939, -0.18735023564939,
    -0.18735023564939, -0.18735023564939, -0.18735023564939, -0.18735023564939,
    -0.18735023564939, -0.18735023564939, -0.18735023564939, -0.18735023564939,
    -0.18735023564939, -0.18735023564939, -0.18735023564939, -0.18735023564939,
    -0.18735023564939, -0.18735023564939, -0.18735023564939, -0.18735023564939,
    -0.18735023564939, -0.18735023564939, -0.18735023564939, -0.18735023564939,
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
float deta8[]={ 0.0104925610639256, 0.0107603227985559, 0.0115685966221744,
    0.0129321213982211, 0.014874708634942, 0.0174281260090492, 0.020630566392732,
    0.0245247454104413, 0.0291556951253379, 0.034568349717293,
    0.0408050465447719, 0.0479030868288826, 0.0558925082280437,
    0.0647942122857754, 0.0746185619534811, 0.0853645211263836,
    0.0970193561421169, 0.109558867263955, 0.1229480747348, 0.137142254975579,
    0.15208821019003, 0.167530916145243, 0.183232150804926, 0.199159328464017,
    0.215280923794422, 0.231566253209406, 0.247985274477157, 0.26450840446592,
    0.281106354532458, 0.297749982955741, 0.314410163894566, 0.331057672554007,
    0.347663086535734, 0.364196703683844, 0.380628477088192, 0.396927968241317,
    0.413064319634172, 0.429006248292304, 0.444722061871279, 0.460179698923934,
    0.475346794802019, 0.490190774346761, 0.504678972050566, 0.51877877973944,
    0.532457821048581, 0.545684151070353, 0.558426478585363, 0.57065440729519,
    0.582338691519204, 0.593451500961433, 0.603966688459016, 0.613860054147588,
    0.623109599265191, 0.63169576289313, 0.639601635308592, 0.646813142288063,
    0.653319195621365, 0.659111806224883, 0.664186157517951, 0.668540638079552,
    0.672176833962924, 0.67509948234669, 0.677316389384938, 0.678838316139445,
    0.679678837303913, 0.679854178046311, 0.679383034699103, 0.678286385228861,
    0.676587295436377, 0.674310726702953, 0.671483350838446, 0.668133377232879,
    0.664290397095095, 0.659985249103243, 0.655249910310755, 0.650117415657013,
    0.644621808922773, 0.638798127432541, 0.632682422210148, 0.626311814592073,
    0.619724589425646, 0.613210629218418, 0.60707698518079, 0.601381031118485,
    0.596168887237173, 0.591474207341955, 0.587317266189682, 0.58370446059669,
    0.58062832509018, 0.578068133034645, 0.575991109537689, 0.574354229013683,
    0.573106516574076, 0.57219172733286, 0.571551248184712, 0.571127055828182,
    0.570864571779353, 0.570715275528459, 0.570638964841348, 0.570605581628403,
    0.570596548384105, 0.570276982847455, 0.569325163234272, 0.567761609127784,
    0.565620144713986, 0.562947322988903, 0.559801593754838, 0.556252190770775,
    0.552377709364228, 0.548264345871904, 0.544003777009397, 0.539690673433932,
    0.535419869511676, 0.531283250985601, 0.527366471087519, 0.523745656823941,
    0.5204843100413, 0.517630629955056, 0.515215474479853, 0.513251132467283,
    0.511731002563993, 0.510327716774848, 0.508720077319684, 0.506897368533287,
    0.504849610873028, 0.50256758901923, 0.500042873384007, 0.497267836043859,
    0.494235661980906, 0.49094035638765, 0.487376748666015, 0.483540493636876,
    0.479428070373655, 0.475036778983804, 0.470364735585567, 0.465410865663908,
    0.460174895938297, 0.454657344835299, 0.448859511629451, 0.442783464295745,
    0.436432026104971, 0.429808760988132, 0.422917957697041, 0.415764612794044,
    0.408354412513557, 0.400693713550964, 0.3927895228494, 0.384649476471326,
    0.376281817658841, 0.367695374203699, 0.358899535264317, 0.349904227782252,
    0.340719892664064, 0.331357460905864, 0.321828329846675, 0.312144339742899,
    0.302317750859186, 0.292361221270951, 0.282287785570224, 0.27211083465958,
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
float deta10[]={ 0.54371365687362916, 0.54399804252074613, 0.54486278486831918,
    0.54634212736068211, 0.54849144216806212, 0.5513847144164622,
    0.55511109952237314, 0.55977065428356421, 0.56546939478014013,
    0.57231389319220716, 0.58040568229721012, 0.58983577856591418,
    0.60067965002369716, 0.61299293435817614, 0.62680815393255718,
    0.64213258378207316, 0.65894732035364612, 0.67720749083558418,
    0.69684345277602511, 0.7177627734955121, 0.73985275321310817,
    0.76253574641877619, 0.78526852616362819, 0.80797838779698017,
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
void loop() 
{   
 int n;
 for (n = 0; n<201; n++){
  myservo1.write(-deta1[n]*180.0/pi + 93);
  myservo2.write(-deta2[n]*180.0/pi + 89);
  myservo3.write(-deta3[n]*180.0/pi + 92);
  myservo4.write(deta5[n]*180.0/pi + 100);
  myservo5.write(deta6[n]*180.0/pi + 92);
  myservo6.write(deta7[n]*180.0/pi + 96);
  myservo7.write(deta8[n]*180.0/pi + 95);
  myservo8.write(deta10[n]*180.0/pi + 80);
  myservo9.write(deta11[n]*180.0/pi + 95);
  myservo10.write(-deta12[n]*180.0/pi + 94);
  delay(20);
 }               
} 
